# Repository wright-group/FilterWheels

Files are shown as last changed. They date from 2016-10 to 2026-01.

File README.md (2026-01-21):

# FilterWheels

Electronics and harware used to automate the process of moving optical filter wheels during experiments.

See documentation.pdf for full information.

## yaq support

The daemons in this repository (`./wright-filter-wheels`) in outdated and unmaintained; instead, use the wright-stepper-motor-box kind found in [`yaqd-wright`](https://github.com/wright-group/yaqd-wright).

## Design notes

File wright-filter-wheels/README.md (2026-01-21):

## Deprecation notice

This set of daemons in outdated and unmaintained; instead, use the `wright-stepper-motor-box` kind found in [`yaqd-wright`](https://github.com/wright-group/yaqd-wright).

# yaqd-wright-filter-wheels








yaq daemon for Wright Group filter wheels

This package contains the following daemon(s):

- https://yaq.fyi/daemons/wright-filter-wheels-continuous

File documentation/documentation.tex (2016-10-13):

% document
\documentclass[11pt]{article}
\usepackage[letterpaper, portrait, margin=1in]{geometry}
\usepackage{setspace}
\usepackage{color}

% text
\usepackage[utf8]{inputenc}
\setlength\parindent{0pt}
\setlength{\parskip}{1em}
\usepackage{enumitem}
\renewcommand{\familydefault}{\sfdefault}
\begin{document}
	
%title
\begin{flushleft}
	{\Huge \textbf{Filter Wheel Documentation}}
\end{flushleft}

%table of contents
{\let\newpage\relax\begin{spacing}{0.1}\tableofcontents\end{spacing}}
\pagebreak
	
\section{Introduction}\label{sec:introduction}

Introduction here please.

\pagebreak
\section{Serial Interface}

The filter wheel control box communicates with other devices through serial commands over USB.

Each command has multiple components seperated by a single space. Commands must be terminated with a carriage return (\texttt{CR} - ASCII 015) and newline (\texttt{NL} - ASCII 012). The same termination is used when the controller responds.

There are just four command syntaxes:

\begin{center}
	\begin{tabular}{r | l}
		\texttt{M [motor index] [steps]} & move relative to current position \\ 
		\texttt{H [motor index]} & home motor \\
		\texttt{Q [motor index]} & query motor \\
		\texttt{U [microstepping integer]} & set micro-stepping integer
	\end{tabular}
\end{center}

The motors are zero-indexed, 0 through 5.

\texttt{steps} can be positive or negative. Positive stepping rotates the wheel clockwise when facing the motor axle. \texttt{steps} is always an integer number of \textit{micro-steps}, so the angular motion will depend on the choice of micro-stepping integer.

Home is defined as the first (micro)step that trips the optical interrupt when approaching clockwise. The controller implicitly handles the special case where the optical interrupt happens to be tripped initially.

When a motor is queried, the controller will send back one of the following:

\begin{center}
	\begin{tabular}{r | l}
		F & fault \\ 
		R & ready \\
		B & busy
	\end{tabular}
\end{center}

Valid micro-stepping integers are 1, 2, 4, 8, 16, \& 32. The controller will default to 1 if an invalid value is set. The controller defaults to 1 during initialization if it is reset or power-cycled.

Commands can be received by the controller at any time. The controller will start motor motion as soon as a command is received, moving motors simultaneously if appropriate. If a command is sent to a motor while \textit{that} motor is still completing the previous command, the new command will immediately replace the old instruction. In general one should use the query command to ensure that a motor is ready before giving it a new instruction.

The controller will respond \texttt{INVALID} when bad commands are sent.

\end{document}

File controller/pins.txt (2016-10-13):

ARDUINO MICRO
MO - NC
SS - NC
1/TX - NC (used by serial)
0/RX - NC (used by serial)
RST - NC
GND - GND
2 - DRIVER 0 STEP
3 - DRIVER 1 STEP
4 - DRIVER 2 STEP
5 - DRIVER 3 STEP
6 - DRIVER 4 STEP
7 - DRIVER 5 STEP
8 - HC259 CLR
9 - HC259 G
10 - HC259 D
11 - HC4351 (HOME) COMMON
12 - HC4351 (FAULT) COMMON
13 - NC
3.3V - NC
AREF - NC
A0 - S0
A1 - S1
A2 - S2
A3 - NC
A4 - DRIVERS M0
A5 - DRIVERS M1
NC - NC
NC - NC
5V - 5V
RST - NC
GND - NC
VI - NC
MI - NC
SCK - NC

HC259
S0 - ARDUINO A0
S1 - ARDUINO A1
S2 - ARDUINO A2
Q0 - DRIVER 0 DIR
Q1 - DRIVER 1 DIR
Q2 - DRIVER 2 DIR
Q3 - DRIVER 3 DIR
GND - GND
Q4 - DRIVER 4 DIR
Q5 - DRIVER 5 DIR
Q6 - NC
Q7 - NC
D - ARDUINO 10
G - ARDUINO 9
CLR - ADRUINO 8
VCC - 5V

HC4351 (HOME)
A4 - MOTOR 4 HOME
A6 - NC
NC - NC
COMMON - ARDUINO 11
A7 - NC
A5 - MOTOR 5 HOME
E1 - GND
E2 - 5V
VEE - GND
GND - GND
LE - 5V
S2 - ARDUINO A2
S1 - ARDUINO A1
NC - NC
S0 - ARDUINO A0
A3 - MOTOR 3 HOME
A0 - MOTOR 0 HOME
A1 - MOTOR 1 HOME
A2 - MOTOR 2 HOME
VCC - 5V

HC4351 (FAULT)
A4 - DRIVER 4 FAULT
A6 - NC
NC - NC
COMMON - ARDUINO 12
A7 - NC
A5 - DRIVER 5 FAULT
E1 - GND
E2 - 5V
VEE - GND
GND - GND
LE - 5V
S2 - ARDUINO A2
S1 - ARDUINO A1
NC - NC
S0 - ARDUINO A0
A3 - DRIVER 3 FAULT
A0 - DRIVER 0 FAULT
A1 - DRIVER 1 FAULT
A2 - DRIVER 2 FAULT
VCC - 5V

DRIVER
ENABLE - NC
M0 - ARDUINO A4
M1 - ARDUINO A5
CONFIG - NC
VREF - NC
SLEEP - 5V
STEP - ARDUINO ...
DIR - HC259 ...
GND - GND
FAULT - HC4351 (FAULT) ...
A2 - DB9 9
A1 - DB9 8
B1 - DB9 7
B2 - DB9 6
GND - GND
VMOT - VMOT

DB9
1 - NC
2 - HOME
3 - 5V
4 - GND
5 - NC
6 - B2
7 - B1
8 - A1
9 - A2

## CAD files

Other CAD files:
controller/enclosure/perforated side.dwg
chassis/large mount - continuous ND/back mount.idw
chassis/large mount - continuous ND/back mount.ipt
chassis/large mount - continuous ND/bottom.idw
chassis/large mount - continuous ND/bottom.ipt
chassis/large mount - continuous ND/coupler.idw
chassis/large mount - continuous ND/coupler.ipt
chassis/large mount - continuous ND/front.idw
chassis/large mount - continuous ND/front.ipt
chassis/large mount - continuous ND/left side.idw
chassis/large mount - continuous ND/left side.ipt
chassis/large mount - continuous ND/post.idw
chassis/large mount - continuous ND/post.ipt
chassis/large mount - continuous ND/right side.idw
chassis/large mount - continuous ND/right side.ipt
chassis/small mount - threaded wheel/OldVersions/bottom.0002.idw
chassis/small mount - threaded wheel/back.idw
chassis/small mount - threaded wheel/back.ipt
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

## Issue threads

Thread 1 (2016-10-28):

add capacitors to protect each integrated circuit

untzag, 2016-10-28:
0.1 uF caps on the supplies of each IC (nearby physically) might help with ICs blowing if motors are hotswitched

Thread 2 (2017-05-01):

no response during "backup" when homing

untzag, 2017-05-01:
If the interrupt is tripped when a home command is sent the wheels back off by a quarter turn before going through the normal homing procedure.

The firmware does not respond to serial communication while the wheels are backing up.

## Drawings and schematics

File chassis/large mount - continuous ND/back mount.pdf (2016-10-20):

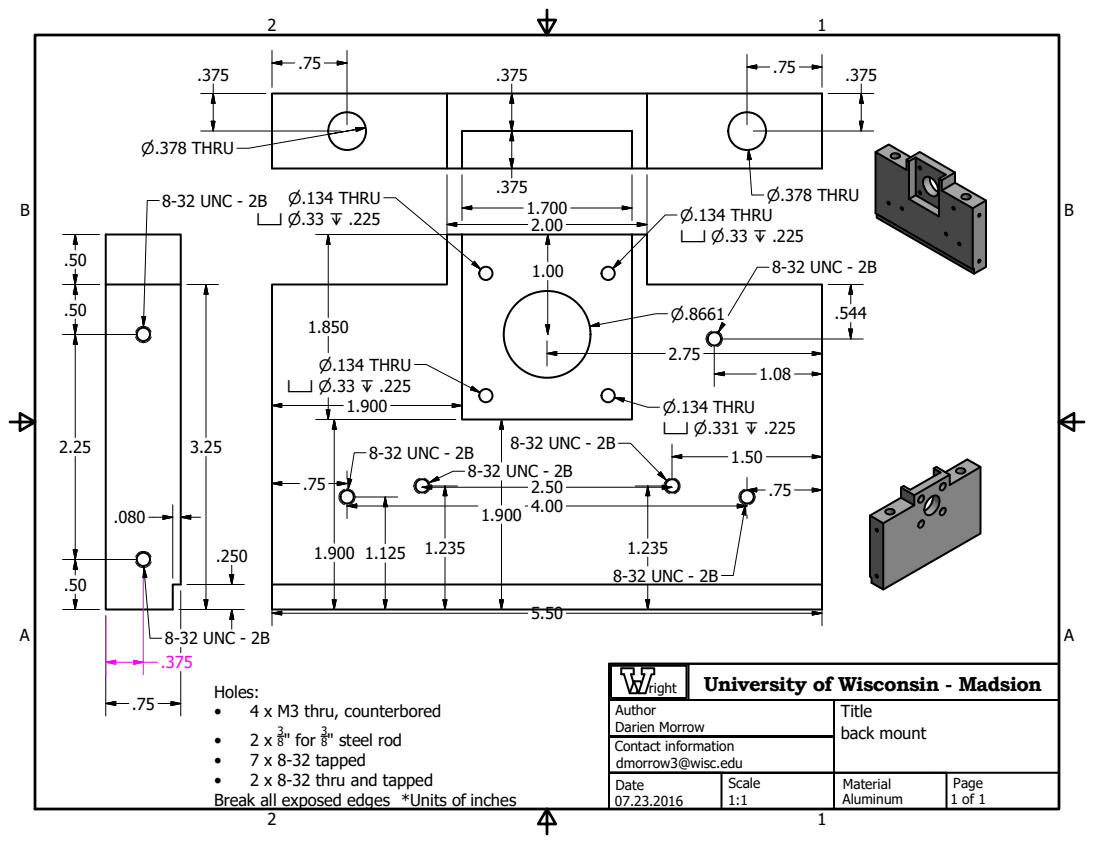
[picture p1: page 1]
Darien Morrow; dmorrow3@wisc.edu; Aluminum; back mount; Author; Date; Scale; Title; Material; Page; Contact information; right; P.378 THRU; 8-32 UNC - 2B 8-32 UNC - 2B; 8-32 UNC - 2B; P.134 THRU X P.33 Z .225; P.134 THRU X P.331 Z .225; 3 8" for; 3 8" steel rod

University of Wisconsin - Madsion

Holes:
• 4 x M3 thru, counterbored
• 7 x 8-32 tapped
• 2 x 8-32 thru and tapped
Break all exposed edges

*Units of inches

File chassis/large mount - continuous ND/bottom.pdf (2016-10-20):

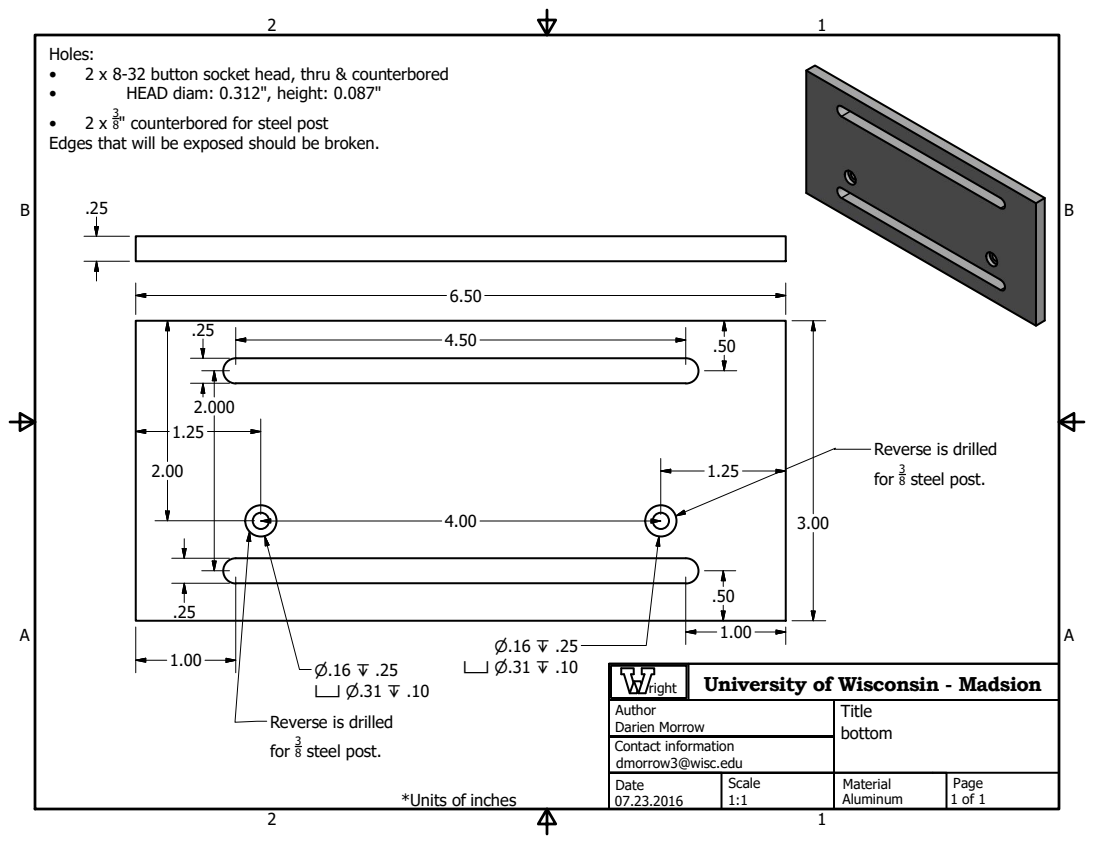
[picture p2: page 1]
Darien Morrow; dmorrow3@wisc.edu; Aluminum; bottom; Author; Date; Scale; Title; Material; Page; Contact information; right; 3 8 steel post.

Holes:
• 2 x 8-32 button socket head, thru & counterbored
• HEAD diam: 0.312", height: 0.087"
Edges that will be exposed should be broken.

8" counterbored for steel post

Reverse is drilled
for

University of Wisconsin - Madsion

*Units of inches

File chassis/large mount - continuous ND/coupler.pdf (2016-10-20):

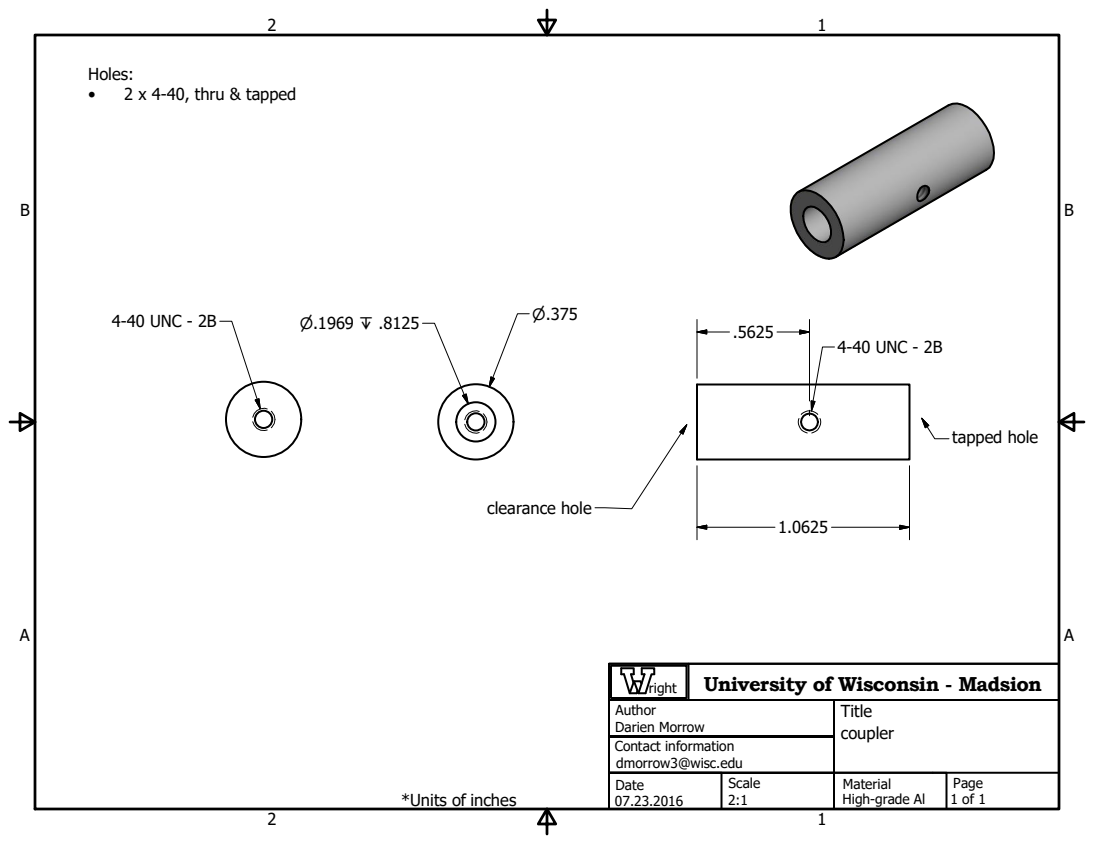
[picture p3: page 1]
Darien Morrow; dmorrow3@wisc.edu; High-grade Al; coupler; Author; Date; Scale; Title; Material; Page; Contact information; right; 4-40 UNC - 2B; clearance hole; tapped hole; Holes: • 2 x 4-40, thru & tapped

University of Wisconsin - Madsion

*Units of inches

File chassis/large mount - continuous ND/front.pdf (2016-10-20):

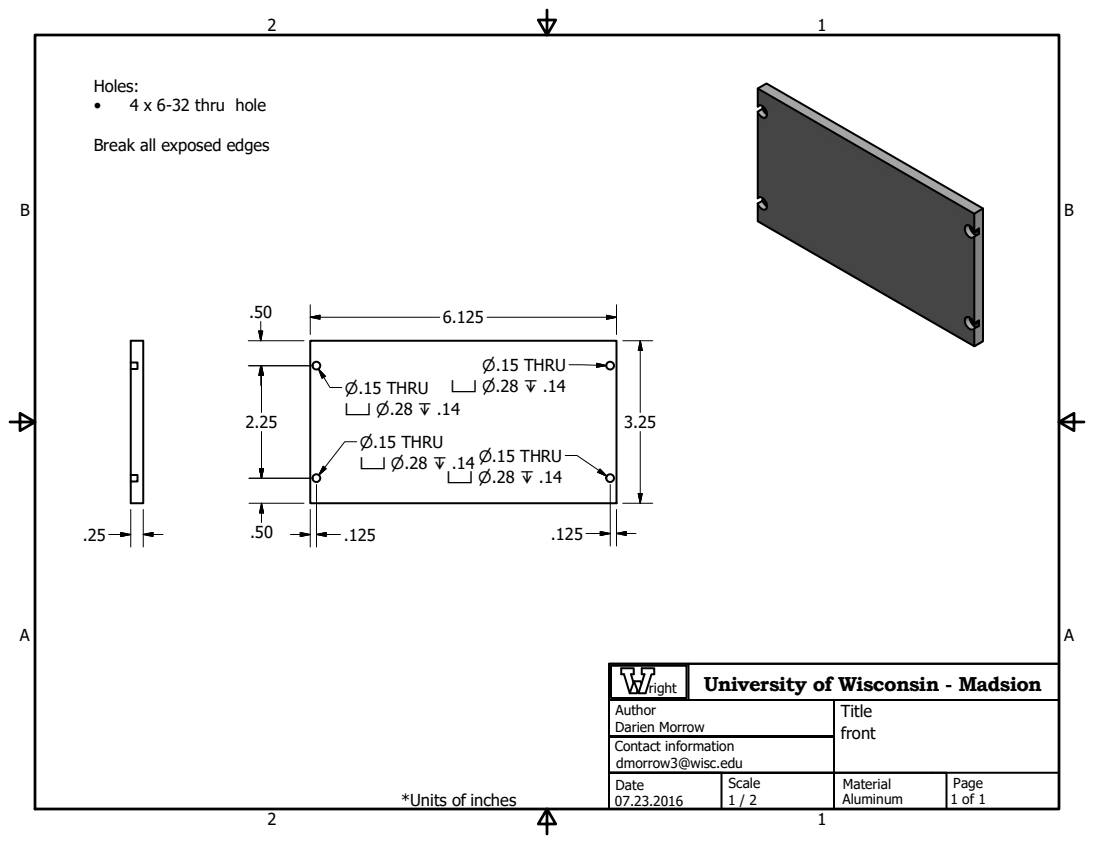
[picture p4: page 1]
Darien Morrow; dmorrow3@wisc.edu; Aluminum; front; Author; Date; Scale; Title; Material; Page; Contact information; right; P.15 THRU X P.28 Z .14; Holes: • 4 x 6-32 thru hole

Break all exposed edges

University of Wisconsin - Madsion

*Units of inches

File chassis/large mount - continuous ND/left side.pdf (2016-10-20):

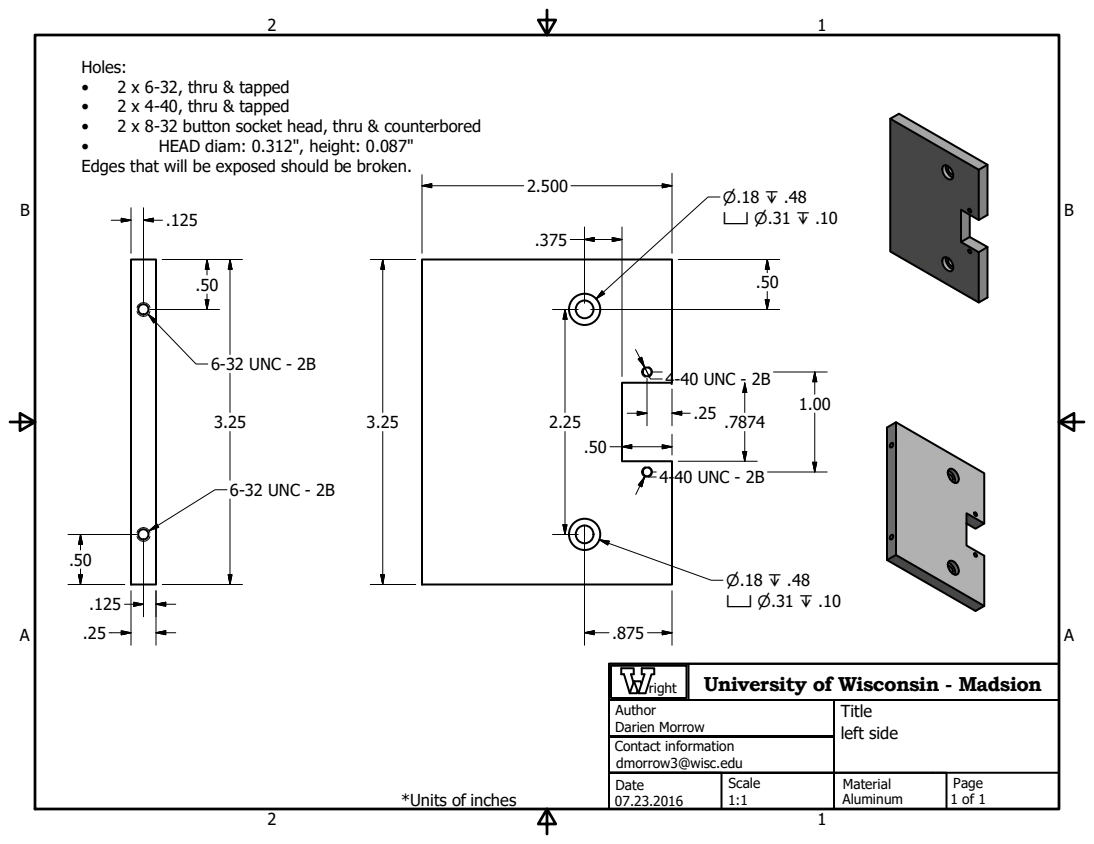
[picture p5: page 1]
Darien Morrow; dmorrow3@wisc.edu; Aluminum; left side; Author; Date; Scale; Title; Material; Page; Contact information; right; 6-32 UNC - 2B; 4-40 UNC - 2B

Holes:
• 2 x 6-32, thru & tapped
• 2 x 4-40, thru & tapped
• 2 x 8-32 button socket head, thru & counterbored
• HEAD diam: 0.312", height: 0.087"
Edges that will be exposed should be broken.

University of Wisconsin - Madsion

*Units of inches

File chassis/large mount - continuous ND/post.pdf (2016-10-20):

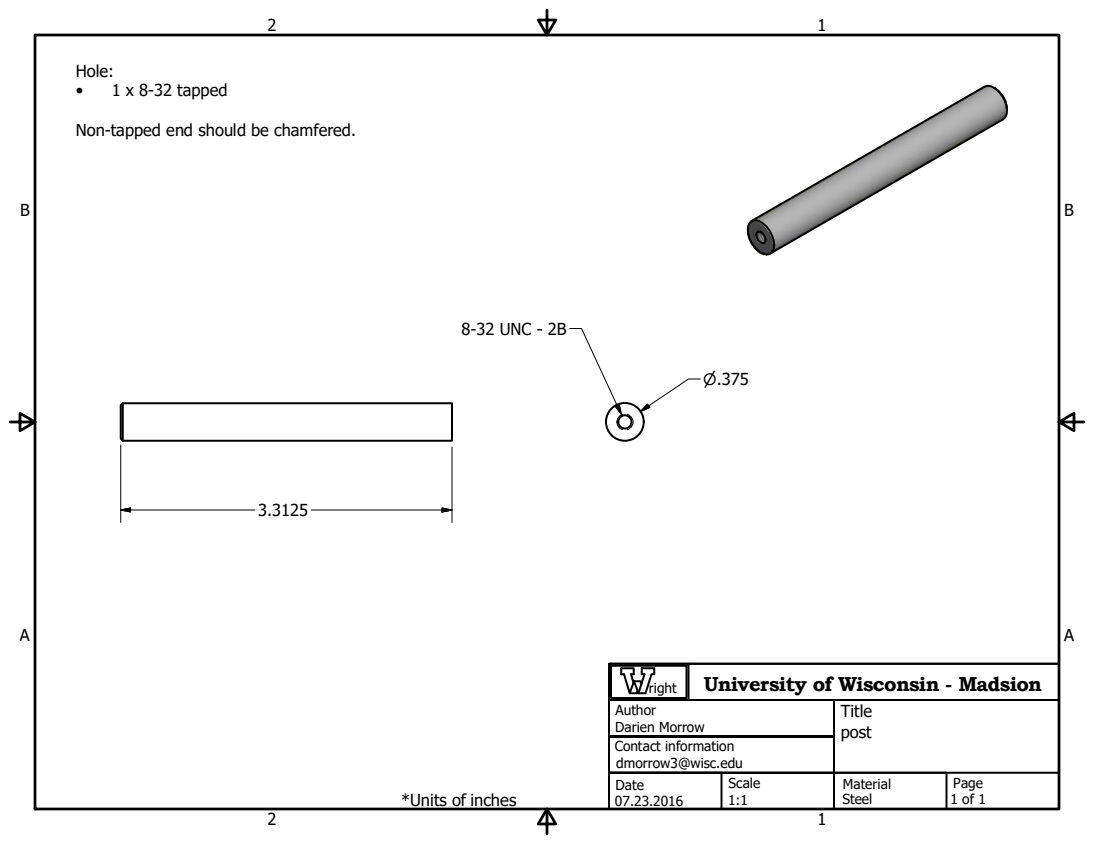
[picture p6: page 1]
Darien Morrow; dmorrow3@wisc.edu; Steel; post; Author; Date; Scale; Title; Material; Page; Contact information; right; 8-32 UNC - 2B; Hole: • 1 x 8-32 tapped

Non-tapped end should be chamfered.

University of Wisconsin - Madsion

*Units of inches

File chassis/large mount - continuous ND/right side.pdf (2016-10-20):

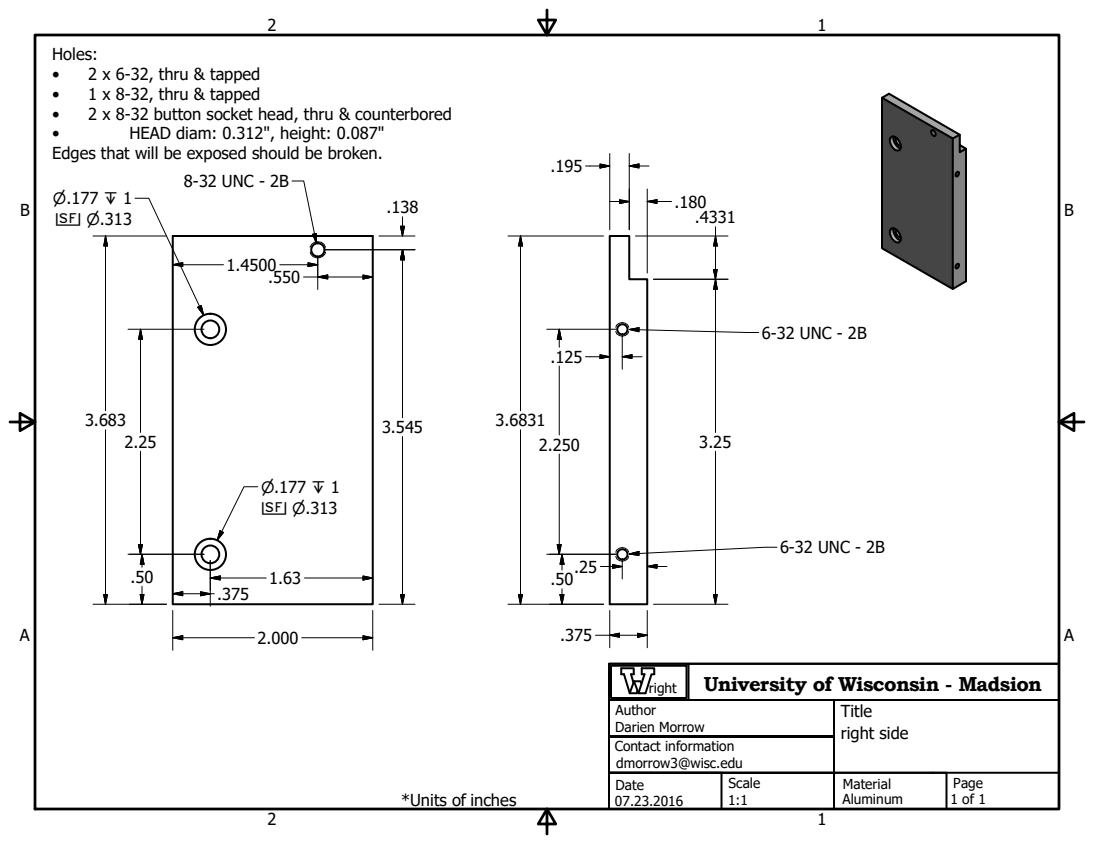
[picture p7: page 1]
Darien Morrow; dmorrow3@wisc.edu; Aluminum; right side; Author; Date; Scale; Title; Material; Page; Contact information; right; 8-32 UNC - 2B; 6-32 UNC - 2B

Holes:
• 2 x 6-32, thru & tapped
• 1 x 8-32, thru & tapped
• 2 x 8-32 button socket head, thru & counterbored
• HEAD diam: 0.312", height: 0.087"
Edges that will be exposed should be broken.

University of Wisconsin - Madsion

*Units of inches

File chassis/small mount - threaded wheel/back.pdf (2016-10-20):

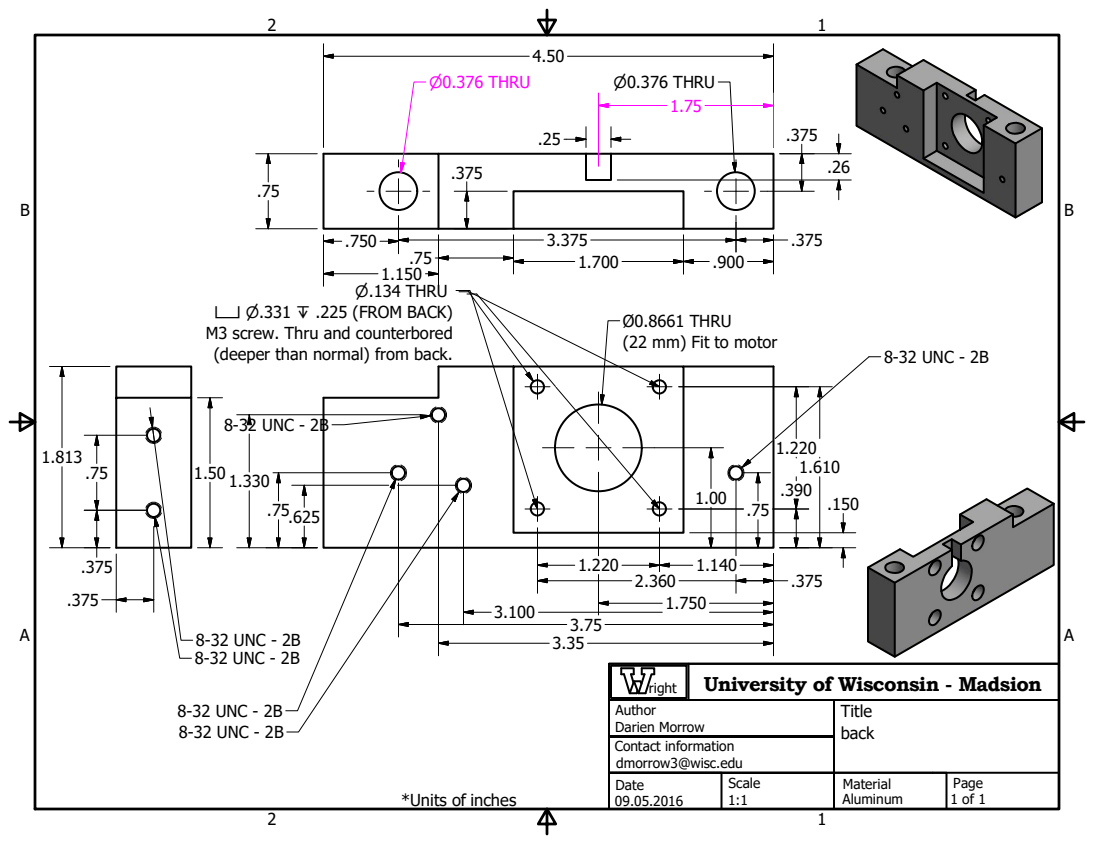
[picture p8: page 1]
Darien Morrow; dmorrow3@wisc.edu; Aluminum; back; Author; Date; Scale; Title; Material; Page; Contact information; right; P0.376 THRU; 8-32 UNC - 2B; 8-32 UNC - 2B 8-32 UNC - 2B; P.134 THRU

X P.331 Z .225 (FROM BACK)
M3 screw. Thru and counterbored
(deeper than normal) from back.

Ø0.8661 THRU
(22 mm) Fit to motor

University of Wisconsin - Madsion

*Units of inches

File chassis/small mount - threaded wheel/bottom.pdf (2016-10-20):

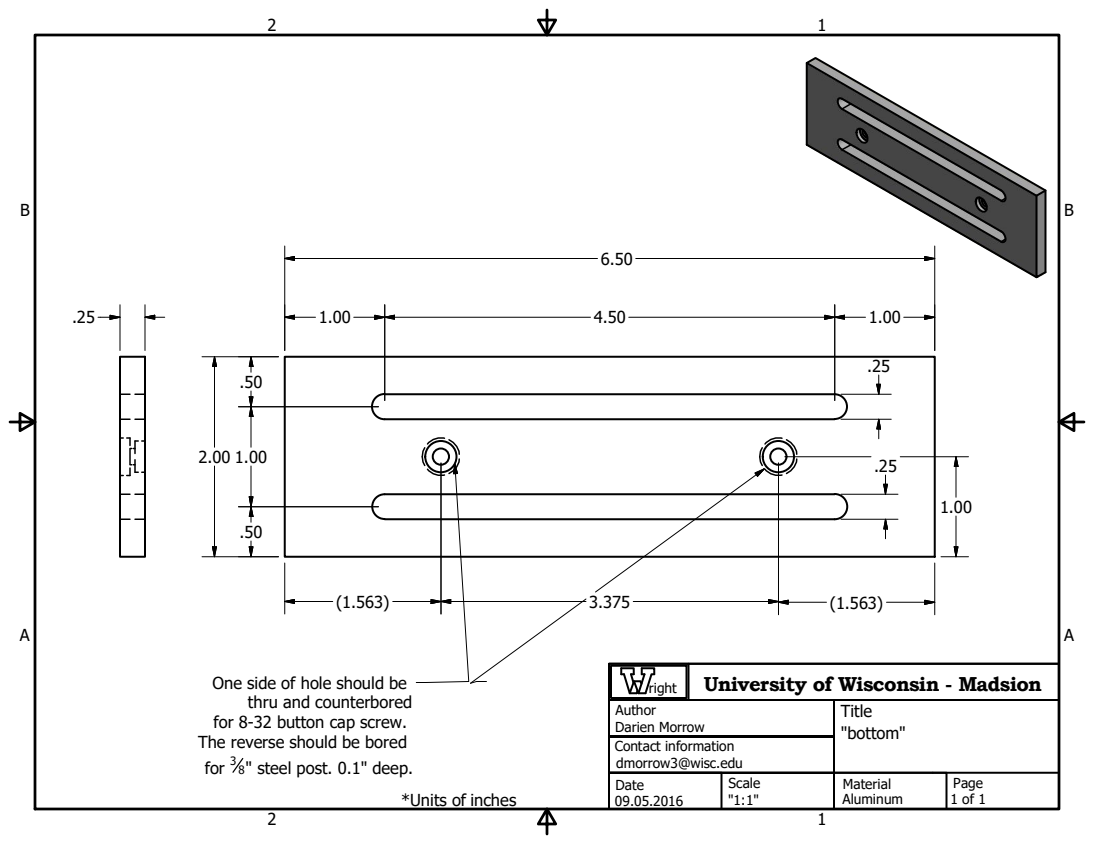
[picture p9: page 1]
Darien Morrow; dmorrow3@wisc.edu; Aluminum; "bottom"; Author; Date; Scale; Title; Material; Page; Contact information; right

One side of hole should be
thru and counterbored
for 8-32 button cap screw.
The reverse should be bored
for

University of Wisconsin - Madsion

8" steel post. 0.1" deep.

*Units of inches

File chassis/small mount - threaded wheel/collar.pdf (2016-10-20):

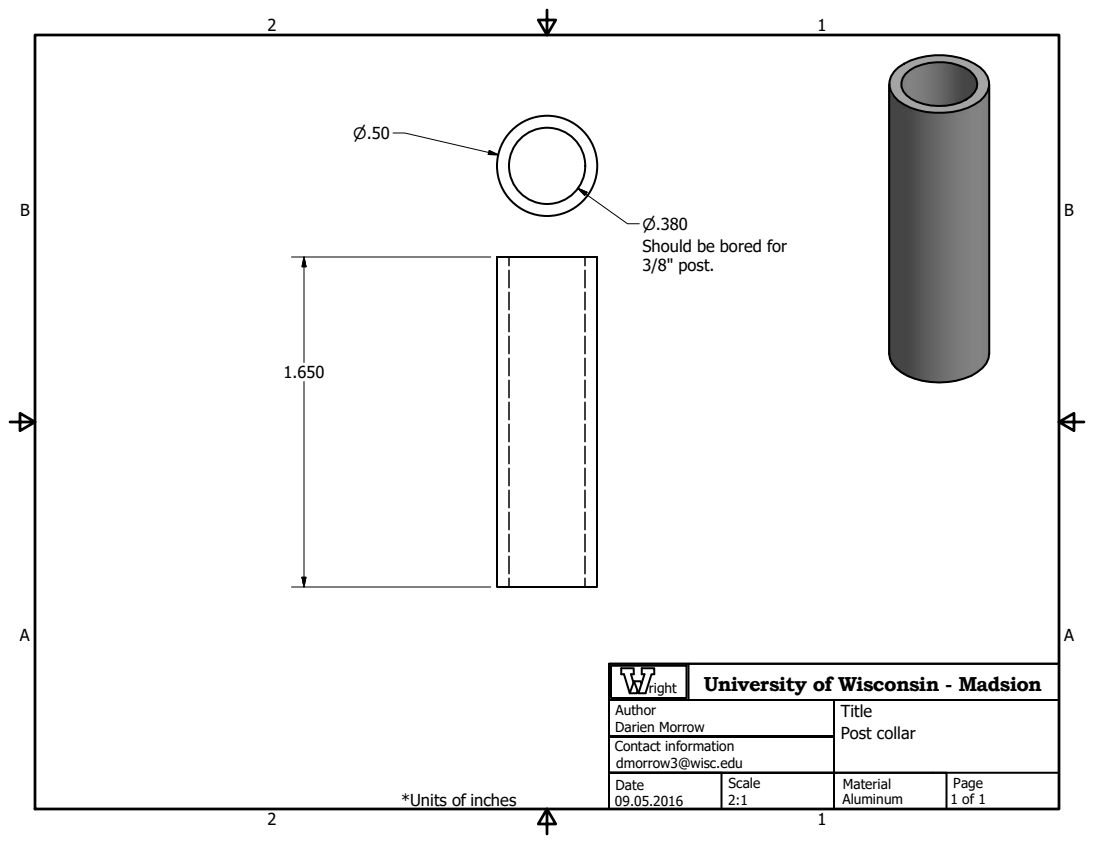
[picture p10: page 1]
Darien Morrow; dmorrow3@wisc.edu; Aluminum; Post collar; Author; Date; Scale; Title; Material; Page; Contact information; right

Should be bored for
3/8" post.

University of Wisconsin - Madsion

*Units of inches

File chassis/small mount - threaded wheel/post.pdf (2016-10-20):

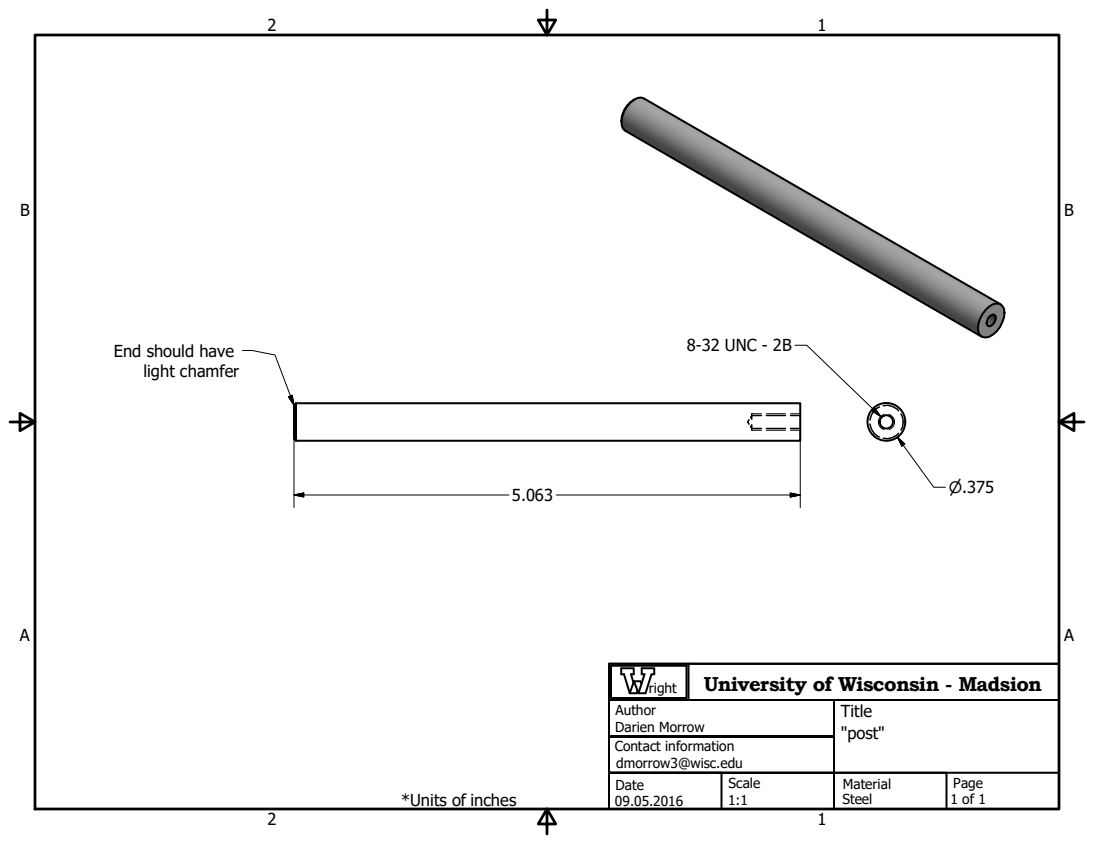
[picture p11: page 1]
Darien Morrow; dmorrow3@wisc.edu; Steel; "post"; Author; Date; Scale; Title; Material; Page; Contact information; right

8-32 UNC - 2B End should have
light chamfer

University of Wisconsin - Madsion

*Units of inches

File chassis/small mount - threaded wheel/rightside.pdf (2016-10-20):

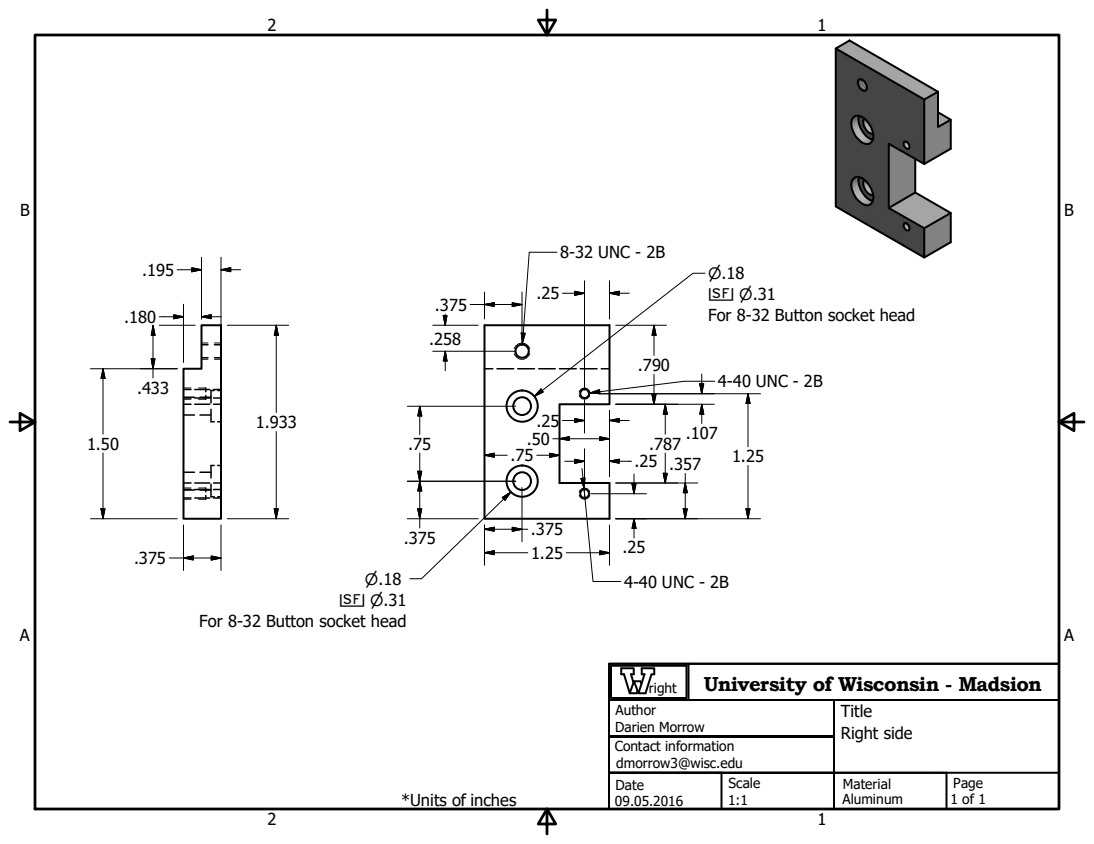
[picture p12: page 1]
Darien Morrow; dmorrow3@wisc.edu; Aluminum; Right side; Author; Date; Scale; Title; Material; Page; Contact information; right; For 8-32 Button socket head; 4-40 UNC - 2B; 8-32 UNC - 2B

For 8-32 Button socket head

University of Wisconsin - Madsion

*Units of inches

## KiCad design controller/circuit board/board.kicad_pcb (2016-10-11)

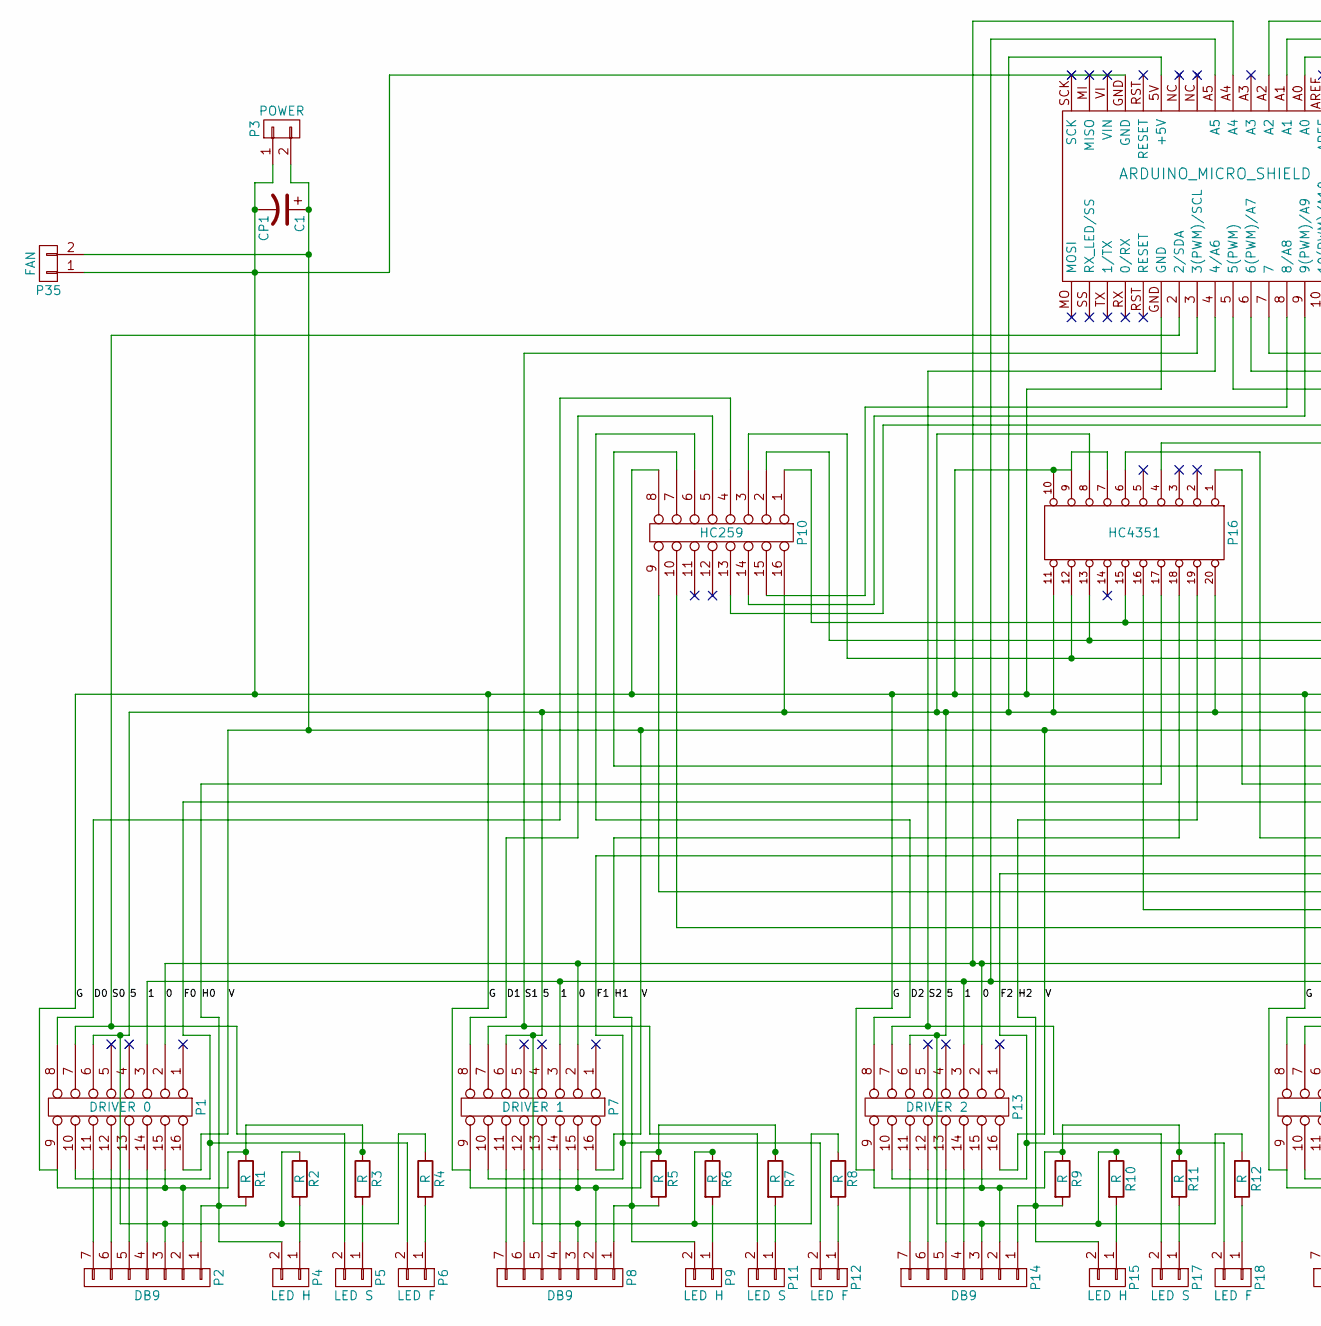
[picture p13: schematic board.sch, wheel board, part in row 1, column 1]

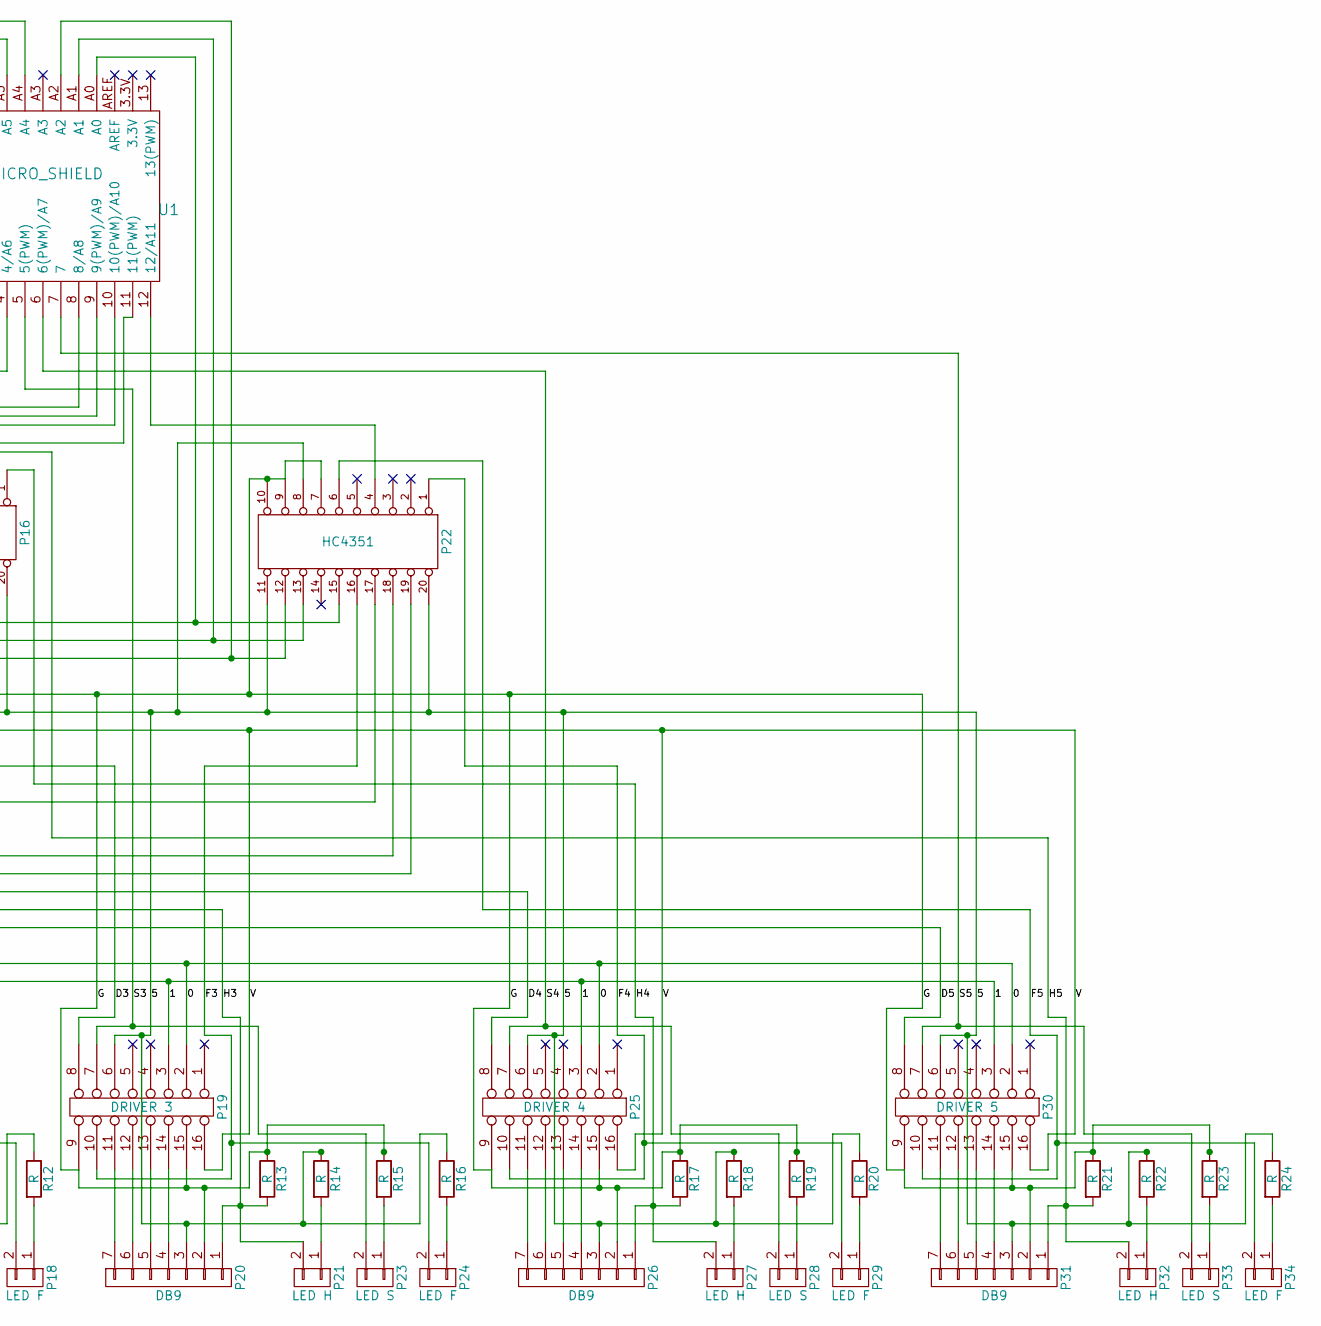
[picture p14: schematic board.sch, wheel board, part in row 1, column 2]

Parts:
C1: CP1; C_Radial_D8_L11.5_P3.5
P1: DRIVER 0; driver
P2, P8, P14, P20, P26, P31: DB9; Pin_Header_Straight_1x07
P3: POWER; WireConnection_2.50mmDrill
P4, P9, P15, P21, P27, P32: LED H; Socket_Strip_Straight_1x02
P5, P11, P17, P23, P28, P33: LED S; Socket_Strip_Straight_1x02
P6, P12, P18, P24, P29, P34: LED F; Socket_Strip_Straight_1x02
P7: DRIVER 1; driver
P10: HC259; DIP-16_W7.62mm
P13: DRIVER 2; driver
P16, P22: HC4351; DIP-20_W7.62mm
P19: DRIVER 3; driver
P25: DRIVER 4; driver
P30: DRIVER 5; driver
P35: FAN; Socket_Strip_Straight_1x02
R1, R2, R3, R4, R5, R6, R7, R8, R9, R10, R11, R12, R13, R14, R15, R16, R17, R18, R19, R20, R21, R22, R23, R24: R; Resistor_Horizontal_RM15mm
U1: ARDUINO_MICRO_SHIELD

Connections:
/0: P1.2, P7.2, P13.2, P19.2, P25.2, P30.2, U1.A4
/1: P1.3, P7.3, P13.3, P19.3, P25.3, P30.3, U1.A5
/5: P1.6, P2.3, P7.6, P8.3, P10.16, P13.6, P14.3, P16.8, P16.11, P16.20, P19.6, P20.3, P22.8, P22.11, P22.20, P25.6, P26.3, P30.6, P31.3, R2.1, R4.1, R6.1, R8.1, R10.1, R12.1, R14.1, R16.1, R18.1, R20.1, R22.1, R24.1, U1.5V (+5V)
/D0: P1.8, P10.4
/D1: P7.8, P10.5
/D2: P10.6, P13.8
/D3: P10.7, P19.8
/D4: P10.9, P25.8
/D5: P10.10, P30.8
/F0: P1.10, P6.2, P22.17
/F1: P7.10, P12.2, P22.18
/F2: P13.10, P18.2, P22.19
/F3: P19.10, P22.16, P24.2
/F4: P22.1, P25.10, P29.2
/F5: P22.6, P30.10, P34.2
/G: C1.2, P1.9, P1.15, P2.2, P3.1, P7.9, P7.15, P8.2, P10.8, P13.9, P13.15, P14.2, P16.7, P16.9, P16.10, P19.9, P19.15, P20.2, P22.7, P22.9, P22.10, P25.9, P25.15, P26.2, P30.9, P30.15, P31.2, P35.1, R1.1, R3.1, R5.1, R7.1, R9.1, R11.1, R13.1, R15.1, R17.1, R19.1, R21.1, R23.1, U1.GND
/H0: P2.1, P4.2, P16.17, R1.2
/H1: P8.1, P9.2, P16.18, R5.2
/H2: P14.1, P15.2, P16.19, R9.2
/H3: P16.16, P20.1, P21.2, R13.2
/H4: P16.1, P26.1, P27.2, R17.2
/H5: P16.6, P31.1, P32.2, R21.2
/S0: P1.7, P5.2, U1.2 (2/SDA)
/S1: P7.7, P11.2, U1.3 (3(PWM)/SCL)
/S2: P13.7, P17.2, U1.4 (4/A6)
/S3: P19.7, P23.2, U1.5 (5(PWM))
/S4: P25.7, P28.2, U1.6 (6(PWM)/A7)
/S5: P30.7, P33.2, U1.7
/V: C1.1, P1.16, P3.2, P7.16, P13.16, P19.16, P25.16, P30.16, P35.2
unnamed: P1.11, P2.7
unnamed: P1.12, P2.6
unnamed: P1.13, P2.5
unnamed: P1.14, P2.4
unnamed: P4.1, R2.2
unnamed: P5.1, R3.2
unnamed: P6.1, R4.2
unnamed: P7.11, P8.7
unnamed: P7.12, P8.6
unnamed: P7.13, P8.5
unnamed: P7.14, P8.4
unnamed: P9.1, R6.2
unnamed: P10.1, P16.15, P22.15, U1.A0
unnamed: P10.2, P16.13, P22.13, U1.A1
unnamed: P10.3, P16.12, P22.12, U1.A2
unnamed: P10.13, U1.10 (10(PWM)/A10)
unnamed: P10.14, U1.9 (9(PWM)/A9)
unnamed: P10.15, U1.8 (8/A8)
unnamed: P11.1, R7.2
unnamed: P12.1, R8.2
unnamed: P13.11, P14.7
unnamed: P13.12, P14.6
unnamed: P13.13, P14.5
unnamed: P13.14, P14.4
unnamed: P15.1, R10.2
unnamed: P16.4, U1.11 (11(PWM))
unnamed: P17.1, R11.2
unnamed: P18.1, R12.2
unnamed: P19.11, P20.7
unnamed: P19.12, P20.6
unnamed: P19.13, P20.5
unnamed: P19.14, P20.4
unnamed: P21.1, R14.2
unnamed: P22.4, U1.12 (12/A11)
unnamed: P23.1, R15.2
unnamed: P24.1, R16.2
unnamed: P25.11, P26.7
unnamed: P25.12, P26.6
unnamed: P25.13, P26.5
unnamed: P25.14, P26.4
unnamed: P27.1, R18.2
unnamed: P28.1, R19.2
unnamed: P29.1, R20.2
unnamed: P30.11, P31.7
unnamed: P30.12, P31.6
unnamed: P30.13, P31.5
unnamed: P30.14, P31.4
unnamed: P32.1, R22.2
unnamed: P33.1, R23.2
unnamed: P34.1, R24.2

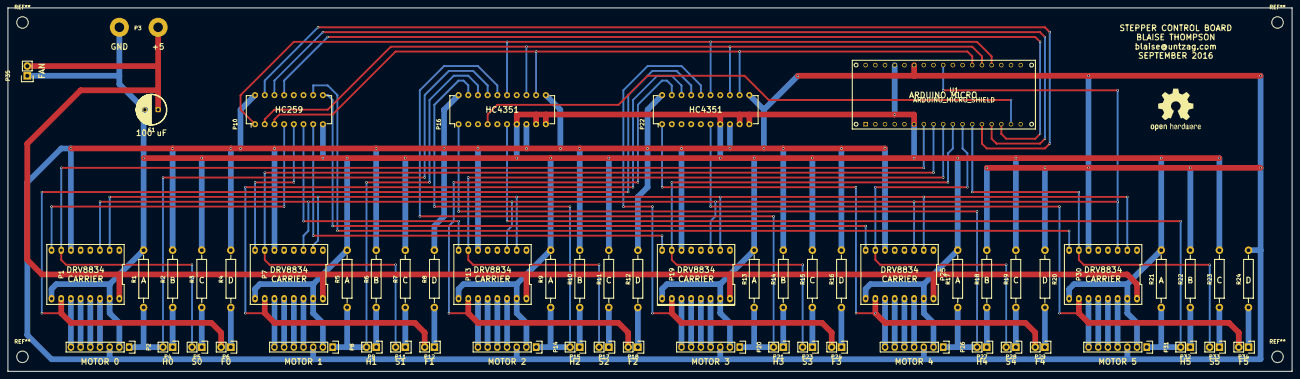
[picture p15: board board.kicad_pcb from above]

Board: 2 copper layers, 336.6 x 95.2 mm, 61 parts (0 on the bottom side), 79 nets.

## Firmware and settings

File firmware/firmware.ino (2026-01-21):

/* multiplexed stepper motor driver
 *
 * stepper controller boards use DRV8834 or similar
 * TI CD74HC4351 multiplexes for steps and microsteps
 * TI SN74HC259 latches motor direction
 *
 * last modified 2026-01-21
 *
*/

// pins
int S0 = A0;
int S1 = A1;
int S2 = A2;
int CLR = 8;
int G = 9;
int D = 10;
int M0 = A4;
int M1 = A5;
int HOME = 11;
int FAULT = 12;
int motors[6] = {2, 3, 4, 5, 6, 7};

// variables
int i = 0;  // for looping
int u = 1;  // microstepping amount
#define INPUT_SIZE 100  // TODO: make this a reasonable value
#define sep " "
char input[INPUT_SIZE + 1];
char code = '0';
char c_index = '0';
char c_number = '0';
int index = 0;
int number = 0;
int remaining[6];
bool home_after[6] = {false, false, false, false, false, false};
unsigned long prev = 0;

void setup() {
  // initialize pins
  pinMode(S0, OUTPUT);
  pinMode(S1, OUTPUT);
  pinMode(S2, OUTPUT);
  pinMode(CLR, OUTPUT);
  pinMode(G, OUTPUT);
  pinMode(D, OUTPUT);
  pinMode(M0, OUTPUT);
  pinMode(M1, OUTPUT);
  pinMode(HOME, INPUT_PULLUP);
  pinMode(FAULT, INPUT_PULLUP);
  for (int i = 0; i < 6; i += 1) {
    pinMode(motors[i], OUTPUT);
  }
  // initialize select
  digitalWrite(S0, LOW);
  digitalWrite(S1, LOW);
  digitalWrite(S2, LOW);
  // initialize latch
  digitalWrite(CLR, HIGH);
  digitalWrite(G, HIGH);
  // initialize microstepping
  setM();
  // initialize direction
  digitalWrite(D, LOW);
  Serial.begin(57600);
  while (!Serial);  // do nothing, waiting for port to connect
}

void loop() {
  // interval comparison avoids overflow issues
  unsigned long waited = millis() - prev;

  if (waited >= 5){
    prev += waited;
    for (i = 0; i <= 5; i++){
      if (remaining[i] > 0) {
        stepMotor(i);
        --remaining[i];
      }  
      else if (home_after[i]) { // ready to home after moving off interrupt
        setSelect(i);
        setDirection(HIGH);
        home_after[i] = false;
        remaining[i] = -1;
      }
      if (remaining[i] == -1) {  // motor currently homing
        setSelect(i);
        stepMotor(i);
        // interrupt is low when blocked
        if (digitalRead(HOME) == 0) remaining[i] = 0;
      }
    }
  }
}

void serialEvent() {  // occurs whenever new data comes in the hardware serial RX
  // read serial into input char array
  byte size = Serial.readBytesUntil('\n', input, INPUT_SIZE);
  input[size] = 0;
  // parse input
  char *code = strtok(input, sep);
  char *c_index = strtok(0, sep);
  char *c_number = strtok(0, sep);
  // convert input
  index = atoi(c_index);
  number = atoi(c_number);  // positive = clockwise (facing motor)
  if (index > 32) {
    Serial.println("INVALID");
    return;
  }
  // call appropriate function
  if (*code == 'M') {  // move relative
    setSelect(index);
    if (number > 0) setDirection(HIGH);
    if (number < 0) setDirection(LOW);
    remaining[index] = abs(number);
  }
  else if (*code == 'H') {  // home motor
    // home is defined as the location where the interrupt 
    //   is first tripped when approaching clockwise
    // first, we must handle the special case where the motor
    //   is already at the interrupt
    setSelect(index);
    if (digitalRead(HOME) == 0) {  // interrupt is low when blocked
      // issue instruction to move 1/4 turn counter-clockwise
      setDirection(LOW);
      remaining[index] = 100 * u;
      // set flag to home after this movement is done
      home_after[index] = true;
    }
    // if interrupt is not blocked, we set remaining to -1, a special code for home
    else {
      setDirection(HIGH);
      remaining[index] = -1;
    }
  }
  else if (*code == 'Q') {  // query motor status
    setSelect(index);
    if (digitalRead(FAULT) == 0) Serial.println('F');
    else if (remaining[index] == 0) Serial.println('R');
    else Serial.println('B');
  }
  else if (*code == 'U') {  // set microstep integer
    u = index;
    setM();
  }
}

void serialEventRun(void) {
  // this runs inside of the main loop, essentially
  if (Serial.available()) serialEvent();
}

void setDirection(int dir) {
  // direction is latched in using TI SN74HC259
  // facing the motor...
  //   LOW = counter clockwise
  //   HIGH = clockwise
  digitalWrite(G, LOW);  // allow value to be written
  digitalWrite(D, dir);
  digitalWrite(G, HIGH);  // lock in value
}

void setSelect(int index) {
  // selection reveals HOME and DIR pins for a specific motor
  digitalWrite(S0, bitRead(index, 0));
  digitalWrite(S1, bitRead(index, 1));
  digitalWrite(S2, bitRead(index, 2));
}

void setM() {
  // set the microstepping control pins
  // for these controllers M0 uses three-state logic
  if (u == 1) {
    pinMode(M0, OUTPUT);
    digitalWrite(M0, LOW);
    digitalWrite(M1, LOW);
  }
  else if (u == 2) {
    pinMode(M0, OUTPUT);
    digitalWrite(M0, HIGH);
    digitalWrite(M1, LOW);
  }
  else if (u == 4) {
    pinMode(M0, INPUT);
    digitalWrite(M1, LOW);
  }
  else if (u == 8) {
    pinMode(M0, OUTPUT);
    digitalWrite(M0, LOW);
    digitalWrite(M1, HIGH);
  }
  else if (u == 16) {
    pinMode(M0, OUTPUT);
    digitalWrite(M0, HIGH);
    digitalWrite(M1, HIGH);
  }
  else if (u == 32) {
    pinMode(M0, INPUT);
    digitalWrite(M1, HIGH);
  }
  else {
    Serial.println("INVALID");
    u = 1;
    setM();
  } 
}

void stepMotor(int index) {
  digitalWrite(motors[index], HIGH);
  delay(1);
  digitalWrite(motors[index], LOW);
}

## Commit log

2016-10-11 add circuit board, firmware, license
    version 0.0.0
    - add circuit board
    - add firmware
    - add gitignore
    - some content for README
    - added LICENSE (CERN Open Hardware Licence v1.2)
    [board-B.Cu.gbl, board-B.Cu.gbr, board-B.Mask.gbr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]
2016-10-13 firmware complete
    version 0.1.0
    - firmware now supports simultanious motor motion
    - firmware now supports directional motion
    - firmware now supports queries (including faults)
    - firmware now supports microstepping
    - added pins and cables records
2016-10-13 termination implementation
    version 0.1.1
    - termination is now explicitly accounted for
    - fixed bugs in reading faults
    - prettified firmware
    [firmware.ino]
2016-10-20 add mechanical drawings
    version 0.2.0
    -added Inventor files and pdf for all machined, mechanical components
    [back mount.idw, back mount.ipt, back.idw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]
2020-06-09 added extra Q,H motor_num, changed microstep function
2020-06-09 additional adjustment of code, procedure for last line of _home needs changing as _destination is NULLed currently and get_position is NULLed
2020-06-16 WIP: changed dir structure, adding identifier test code, current fail at toml.load
2026-01-21 firmware: reduce serial latency (#5)
    * main loop: delay -> mllis
    * issue #2
    * Update firmware.ino
    * less digital writes
    only call `setSelect` when we have something to do
    * cleanup
    * Update firmware.ino
    * Update firmware.ino
    * safe for millis overflow
    * cleanup
    * add meta
    [firmware.ino]
